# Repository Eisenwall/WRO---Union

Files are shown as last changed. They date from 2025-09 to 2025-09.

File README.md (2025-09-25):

# WRO---Union
# Team Union — Obelix (WRO Future Engineers 2025)

**Project name:** Obelix — Autonomous Robot  
**Team name:** Union  
**Team members:**  
- Abdullah Beshirov — Tester  
- Murad Mehdi — Programmer  
- Jamil Hajizade — Designer  

**GitHub account:** [Eisenwall](https://github.com/Eisenwall)  
**YouTube channel:** N/A  

---

## Project Overview

Our team, Union, has developed **Obelix**, an autonomous robot designed for the **WRO Future Engineers 2025** competition. The primary objective of Obelix is to navigate an obstacle-laden arena autonomously, detect and avoid objects using sensors, and maintain precise movement control with high reliability. Obelix has been developed in two versions: **Obelix 1.0** (prototype) and **Obelix 2.0** (final model). Each version demonstrates progressive improvements in mechanical design, sensor integration, and driving control systems.

We are a dedicated, goal-oriented, and hardworking team. Abdullah Beshirov focused on testing, Murad Mehdi handled programming, and Jamil Hajizade designed the mechanical and aesthetic parts of the robot. Together, we aimed to optimize the robot for maximum efficiency and accuracy on the competition field.

---

## Robot Versions

### Obelix 1.0 (Prototype)

Obelix 1.0 served as the prototype for testing sensor integration, motor control, and mechanical design. Its specifications include:

**Components:**
- **Motors:** 1 × Force-Up 6V 1000 RPM Carbon Brushed DC Motor  
  - Specially manufactured for professional mini sumo robots  
  - High torque and speed suitable for competitions  
  - 6V operating voltage (up to 12V for increased speed and torque)  
  - Specifications:
    - Operating Voltage: 6–12V  
    - Max Voltage: 12V  
    - Speed: 1000 RPM (6V)  
    - No-load Current: 30 mA (6V)  
    - Stall Current: 3.2 A (6V)  
    - Torque: 2.1 kg/cm nominal, 3.7 kg/cm stall  
    - Weight: 9.5 g  
- **Servo:** 1 × SG90 for steering front wheels via **Ackerman steering system**  
- **Ultrasonic Sensors:** 4 × HC-SR04 (1 front, 2 sides, 1 rear)  
- **Color Sensor:** TCS3200, positioned at the front of the robot  
- **Microcontroller:** Arduino Uno  
- **Voltage Regulator:** XL4015 to supply motors with correct voltage  
- **Power Supply:** 2 × Li-ion 18650 for Arduino, 6 × AA batteries for motors  
- **Motor Driver:** TB6612FNG (free-floating due to mechanical design)  
- **Differential system:** Custom LEGO-based differential with three inner gears transmitting motor torque to wheels  
- **Wheels and Steering:** Front wheels connected via Ackerman system using bolts and approximately 40 wires forming tire-like structures using bicycle tube material  

This version used differential drive for two wheels, controlled via the Arduino and color sensor for environmental feedback. The layout optimized sensor placement and power distribution to avoid interference with mechanical components.

---

### Obelix 2.0 (Final Model)

Obelix 2.0 incorporates mechanical and electronic improvements, including:

**Major Upgrades:**
- Replaced Ackerman steering with **Solid Axle Steering system** for increased stability  
- Added a **toggle switch** for motor power control  
- Updated motor: **Force-Up 6V 625 RPM Carbon Brushed DC Motor**  
  - Designed for mini sumo robots with high durability and reliability  
  - Specifications:
    - Operating Voltage: 6–12V  
    - Max Voltage: 12V  
    - Speed: 625 RPM (6V)  
    - No-load Current: 40 mA (6V)  
    - Stall Current: 2.6 A (6V)  
    - Torque: high enough for obstacle navigation  
    - Weight: 9.5 g  

All other components (ultrasonic sensors, color sensor, Arduino Uno, XL4015, battery setup) remained the same. The changes improved maneuverability, stability, and energy efficiency while maintaining the same overall robot footprint.

---

## Folder Structure

obelix/
│
├── obelix 1.0/
│ ├── README.md
│ ├── instructions_to_create.txt
│ ├── how_it_works
│ └── components/
│ └── details.txt (3D models uploaded separately)
│
├── obelix 2.0/
│ ├── new_changes.txt
│ ├── instructions_to_create.txt
│ ├── how_it_works
│ ├── how_it_looks
│ └── components/
│ └── details.txt (3D models uploaded separately)
│
└── README.md (this file)

pgsql
Копировать код

- `obelix 1.0/` contains all prototype documentation, assembly instructions, and 3D models.  
- `obelix 2.0/` includes the latest version documentation, updates compared to 1.0, assembly instructions, and component list.  
- `README.md` summarizes the entire project, robot specifications, and team details.

---

## How It Works

Obelix navigates using **ultrasonic sensors** to measure distances and a **TCS3200 color sensor** to detect markers or lines. Two motors are driven via **differential drive**, while the front wheels steer according to either the Ackerman (1.0) or Solid Axle (2.0) system. The Arduino reads sensor inputs, calculates steering adjustments, and controls motor speed and servo position in real time.

The robot intelligently adjusts its path based on distance changes from obstacles, ensuring efficient navigation and obstacle avoidance. The system handles complex turns and detects objects approaching from different angles.

---

## Sample Arduino Code

```cpp
#include <Servo.h>
Servo myServo;

#define PWMA A3
#define AIN1 A4
#define AIN2 A5

#define TRIG_F 2
#define ECHO_F 3

#define TRIG_R 4
#define ECHO_R 5

#define TRIG_L 6
#define ECHO_L 7

#define TRIG_B 8
#define ECHO_B 9

float prevR = 0, currR = 0, prevL = 0, currL = 0, prevB = 0, currB = 0, prevF = 0, currF = 0;
long duration;
int servoPos = 89;
int stepCount = 0;
int x;
bool xSet = false;

float getDistance(int trigPin, int echoPin) {
  digitalWrite(trigPin, LOW);
  delayMicroseconds(2);
  digitalWrite(trigPin, HIGH);
  delayMicroseconds(10);
  digitalWrite(trigPin, LOW);

  duration = pulseIn(echoPin, HIGH, 20000);
  if(duration == 0) return 9999;
  return (duration * 0.0343) / 2;
}

void setup() {
  pinMode(TRIG_R, OUTPUT);
  pinMode(ECHO_R, INPUT);
  pinMode(TRIG_L, OUTPUT);
  pinMode(ECHO_L, INPUT);
  pinMode(TRIG_B, OUTPUT);
  pinMode(ECHO_B, INPUT);
  pinMode(TRIG_F, OUTPUT);
  pinMode(ECHO_F, INPUT);

  myServo.attach(A2);
  myServo.write(servoPos);
  delay(300);

  pinMode(PWMA, OUTPUT);
  pinMode(AIN1, OUTPUT);
  pinMode(AIN2, OUTPUT);

  digitalWrite(AIN1, HIGH);
  digitalWrite(AIN2, LOW);
  analogWrite(PWMA, 255);

  Serial.begin(9600);
}

void loop() {
  if (stepCount >= 12) {
    analogWrite(PWMA, 0);
    myServo.write(89);
    while (true) {}
  }

  prevR = currR;
  currR = getDistance(TRIG_R, ECHO_R);
  prevL = currL;
  currL = getDistance(TRIG_L, ECHO_L);
  prevB = currB;
  currB = getDistance(TRIG_B, ECHO_B);
  prevF = currF;
  currF = getDistance(TRIG_F, ECHO_F);

  float diffR = currR - prevR;
  float diffL = currL - prevL;
  float diffB = currB - prevB;
  float diffF = currF - prevF;

  if(!xSet){
    if (currL < 18 && currF > currB) x = 1;
    else if (currL < 18 && currF < currB) x = 2;
    else if (currL > 70 && currF < currB) x = 3;
    else if (currL > 70 && currF > currB) x = 4;
    else if (currR < 35 && currF < currB) x = 5;
    else if (currR < 35 && currF > currB) x = 6;
    else if (currR > 55 && currF > currB) x = 7;
    else if (currR > 55 && currF < currB) x = 8;
    xSet = true;
  }

  if(currL > 125 && currB > 150){
    myServo.write(62);
    delay(670);
    servoPos = 89;
    myServo.write(servoPos);
    stepCount++;
  } else if(currR > 125 && currB > 140){
    myServo.write(114);
    delay(670);
    servoPos = 89;
    myServo.write(servoPos);
    stepCount++;
  }

  if (currL < 150 && currR < 150) {
    if(diffR > 0.5 || diffL < -0.5) servoPos = 98;
    else if(diffR < -0.5 || diffL > 0.5) servoPos = 80;
    else servoPos = 89;
    myServo.write(servoPos);
    delay(10);
  }
}

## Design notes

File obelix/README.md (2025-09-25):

# WRO---Union
# Team Union — Obelix (WRO Future Engineers)

**Project name:** Obelix — Self-Driving Car (WRO Future Engineers)  
**Team name:** Union  
**Team members:** Abdullah Beshirov, Murad Mehdi, Jamil Hajizade  
**GitHub account:** Eisenwall  
**Repository structure:** `obelix/` contains `obelix_1.0/` and `obelix_2.0/` folders, documentation and code.

---

## 1. Project overview

This repository contains the design, firmware, mechanical notes and media for the Obelix self-driving vehicle developed by Team Union for the WRO Future Engineers category. The project has two main hardware versions:

- **Obelix 1.0** — initial prototype using Ackerman steering mechanism and the following sensors and components (see Hardware).  
- **Obelix 2.0** — improved final model using Solid Axle Steering system, improved motor and power-switch, structure and wiring improvements. The `obelix_2.0/new_changes` folder documents differences compared to Obelix 1.0.

The focus of the project is robust autonomous lane keeping, pillar (traffic sign) recognition (colour classification), obstacle avoidance using ultrasonic sensors, and reliable parallel parking manoeuvre. All documentation and source code included here aims to be reproducible for other teams.

---

## 2. Team and responsibilities

- **Abdullah Beshirov** — mechanical assembly, differential and drivetrain  
- **Murad Mehdi** — sensors integration, electronics wiring, power management  
- **Jamil Hajizade** — firmware, algorithms (obstacle avoidance and parking), repository & documentation

---

## 3. Short summary of Obelix 1.0 and 2.0

**Obelix 1.0 (prototype)**  
- Steering: **Ackerman steering mechanism** for front wheels.  
- Drive: differential power applied to the rear axle via a LEGO-based differential assembly. Two driving wheels powered by a single driving axle with differential gearing derived from LEGO parts (small gear + cross shafts).  
- Motors: 1 × *Force-Up 6V 1000 RPM* brushed DC motor (high torque).  
- Steering servo: 1 × SG90 (controls front pair via Ackerman linkages).  
- Sensors: 4 × HC-SR04 ultrasonic sensors (front, left, right, rear), 1 × TCS3200 color sensor (front).  
- Controller: **Arduino Uno** (main control and sensor reading).  
- Motor driver: **TB6612FNG** (drives DC motor; mounted on the chassis but not rigidly fixed).  
- Power: 2 × 18650 Li-ion cells for Arduino power and 6 × AA batteries for motor supply; XL4015 module used for regulating motor supply where necessary.  
- Chassis, tires: custom chassis, drive shafts and a tire made from bicycle camera rubber for traction.

**Obelix 2.0 (final)**  
- Steering: **Solid Axle Steering** (mechanically simpler and more robust). Ackerman replaced.  
- Motor replaced with **Force-Up 6V 625 RPM** (lower RPM, higher torque).  
- Added main toggle switch (tumbler) for motor on/off.  
- Wiring, cabling and battery sockets reorganised for reliability.  

---

## 4. Hardware (detailed list)

All components (more details in `obelix/*/components/details.txt`):

- Arduino UNO — 1 pcs  
- HC-SR04 Ultrasonic sensor — 4 pcs (front, left, right, rear)  
- TCS3200 Color sensor — 1 pcs (front)  
- SG90 micro servo — 1 pcs (steering for Obelix 1.0)  
- Force-Up DC Motor (6V, 1000 RPM) — Obelix 1.0 — 1 pcs  
- Force-Up DC Motor (6V, 625 RPM) — Obelix 2.0 — 1 pcs  
- Motor driver TB6612FNG — 1 pcs  
- XL4015 (step-down / current regulator) — 1 pcs  
- Li-ion 18650 battery holder / 2 cells — 1 set (for Arduino)  
- AA battery holder (6×AA) — 1 set (for motor pack)  
- Breadboard (partial removed piece used in chassis) — small section mounted on back  
- Mechanical parts: LEGO differential piece + cross axles, custom links for Ackerman, bolts (Ø3mm × 15mm and smaller), cable ties, wheel rims, rubber tyre (from bicycle camera)  
- Cables: ~40 wires used for traction banding and wiring

(See `BOM.csv` for table version.)

---

## 5. Software architecture and files

This project uses a single microcontroller (Arduino Uno) as main controller for both sensors and actuators. The code is organized as:

/code  
/arduino  
obelix.ino <-- main firmware  
drive_control.h/.cpp  
sensors.h/.cpp  
config.h <-- pin mapping, thresholds and calibration constants  

/tools  
serial_logger.py <-- optional serial log viewer (desktop)

**Main behaviour (firmware)**:  
- Read sensors (HC-SR04 x4, TCS3200)  
- Low-level motor control through TB6612FNG (PWM and direction)  
- Steering control through SG90 (PWM for Ackerman) or Solid Axle linkage in v2.0  
- Finite state machine for: `WAIT_START -> LANE_FOLLOW -> PILLAR_HANDLING -> PARKING_MANEUVER -> STOP`  
- Logging via Serial (for debug)

---

## 6. Pin mapping (recommended, edit `config.h` as needed)

- HC-SR04 front: TRIG D2, ECHO D3  
- HC-SR04 left: TRIG D4, ECHO D5  
- HC-SR04 right: TRIG D6, ECHO D7  
- HC-SR04 rear: TRIG D8, ECHO D9  
- TCS3200 S0..S3: D10..D13 (or analog read if using frequency counting)  
- Servo: D11 (PWM)  
- TB6612FNG: PWM_A D5, AIN1 D12, AIN2 D13 (adjust as needed)  
- Start push button: digital pin A0 (if used)

---

## 7. How to build / compile / upload (Arduino)

1. Install Arduino IDE (latest stable).  
2. Open `code/arduino/obelix.ino`.  
3. Edit `config.h` to match your wiring (pins and battery voltages).  
4. Select board `Arduino Uno`, correct COM port.  
5. Compile and Upload.  
6. Place robot in starting zone, switch batteries on, press start (or send serial start if configured).

---

## 8. Tests, videos and performance

**Videos:** Put links in `videos.txt` and in this README when uploaded (YouTube unlisted/public). Each challenge must have at least one demo ≥30 seconds.

**Expected Behaviours:**  
- Lane follow stable (tested on practice mat)  
- Pillar detection via TCS3200 (red vs green classification)  
- Parallel parking routine triggered after lap completion

---

## 9. Reproducibility & files to reproduce the build

- `obelix_1.0/components/details.txt` — component list and small CAD notes  
- `obelix_1.0/instructions_to_create.txt` — assembly guide (mechanical connections, bolts, link lengths)  
- `obelix_2.0/new_changes/*` — changes from 1.0 to 2.0  
- `/models` — STL / CAD files (3D models to be uploaded)  
- `docs/wiring_diagram.png` — wiring diagram (add when available)

---

## 10. Commit history requirements (WRO)

- Commit 1 — not later than 2 months before competition (≥20% of final code)  
- Commit 2 — not later than 1 month before competition  
- Commit 3 — not later than 2 weeks before competition  

Repository must be **public** for at least 12 months.

---

## 11. Licence & credits

- MIT License (`LICENSE`)  
- Hardware components: suppliers listed in BOM  
- Team-built mechanical parts and software modules credited in `CREDITS.md`

---

## 12. Contact

Team Union — Team Captain: Jamil Hajizade — `<<team.email@example.com>>`

---

# Engineering Journal — Team Union — Obelix

**Team:** Union  
**Robots:** Obelix 1.0 (prototype), Obelix 2.0 (final)  
**Authors:** Abdullah Beshirov, Murad Mehdi, Jamil Hajizade  

---

## Entry 1 — Mobility Management (design & choices)
**Date:** 2025-09-25  
**Goal:** Design reliable drivetrain and steering that meet WRO rules (4 wheels, one driving axle, one steering actuator).  

**Components used:**  
- Drive motor (Obelix 1.0): Force-Up 6V 1000 RPM  
- Drive motor (Obelix 2.0): Force-Up 6V 625 RPM  
- Differential assembly: LEGO differential piece + cross shafts  
- Steering: SG90 + Ackerman linkage (v1.0); Solid Axle (v2.0)  

**Design rationale:**  
- Single driving axle with differential complies with WRO rules. LEGO differential allows independent wheel rotation.  
- Ackerman servo used for simplicity; replaced with Solid Axle for repeatable steering in final version.  
- Bicycle camera rubber used on rims for traction.  

**Testing:**  
- 10 straight runs at 6V; corrected slight right drift by adjusting servo and mounting.  
- Overheating risk tested; duty cycles recommended.

---

## Entry 2 — Power & Sensor Management
**Date:** 2025-09-25  
**Power system:**  
- Arduino: 2 × 18650 Li-ion (regulated).  
- Motors: 6 × AA batteries, TB6612FNG, XL4015 for regulation.  
- Obelix 2.0: added main toggle switch.  

**Sensors:**  
- HC-SR04 x4 for obstacle detection (front, left, right, rear)  
- TCS3200 for pillar colour detection  

**Testing & measurements:**  
- Idle motor current ~30–40 mA; stall 2.6–3.2 A  
- Ultrasonic reliable for 5–200 cm, filtered in firmware  

---

## Entry 3 — Obstacle Management & Algorithms
**Date:** 2025-09-25  
**Goal:** Describe obstacle and parking strategy  

**Strategy summary:**  
- Finite state machine:  
  - `START` → `FOLLOW_LANE` → while laps < 3: `PILLAR_RESPONSE` → if lap_complete: `PARKING_SEQUENCE` → `STOP`  
- PILLAR_RESPONSE:  
  - TCS3200 reads pillar colour  
  - GREEN → left-bias trajectory  
  - RED → right-bias trajectory  
- LANE FOLLOW:  
  - Ultrasonic left+right sensors for lane centering  
  - Front sensor for obstacle proximity  
- PARKING:  
  - Predefined parallel parking trajectory using distances (coordinate-free)

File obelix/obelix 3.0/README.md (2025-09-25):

# Team Union — Obelix 3.0 (WRO Future Engineers)

**Project name:** Obelix 3.0 — Self-Driving Car (WRO Future Engineers)  
**Team name:** Union  
**Team members:** Abdullah Beshirov, Murad Mehdi, Jamil Hajizade  
**GitHub account:** Eisenwall

It will be the third version of the robot
We divided it into three versions:
obelix 3.0 (basic version) and obelix 3.0 modified
## ⚙️ Comparison Table

| Feature | Obelix 3.0 (Basic) | Obelix 3.0 Modified |
|---|---|---|
| Ultrasonic sensors | 2 (front on servo + rear fixed) | None |
| Color sensor | TCS3200 + lens (on servo) | None |
| Camera | No | OV2640 (ESP32-CAM) / Pi Camera v3 |
| Microcontroller | Arduino Uno / Mega | ESP32-CAM / Raspberry Pi 4 |
| Motors | NovaMax Enkoderli 6V 500 RPM | NovaMax Enkoderli 6V 500 RPM |
| Switch | ON/OFF switch | ON/OFF switch |
| Servos | SG90 (ultrasonic + TCS3200) | SG90 (camera pan) |

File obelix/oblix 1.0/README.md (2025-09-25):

## Obelix 1.0 — Prototype
The first version of our robot was mainly focused on testing ideas and validating the base concept.  
- **Pros:**  
  - Ackerman steering system allowed good maneuverability.  
  - High-speed 1000 RPM motor provided fast movement.  
  - Easy to assemble with LEGO-based differential and 3D printed parts.  
- **Cons:**  
  - Steering system was unstable and hard to control at higher speeds.  
  - Battery and wiring layout was less practical.  
  - Robot was less reliable for long runs.

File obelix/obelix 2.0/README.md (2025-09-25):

## Obelix 2.0 — Final Model
The second version was redesigned to be more stable, reliable, and competition-ready.  
- **Pros:**  
  - Solid Axle Steering improved handling and overall stability.  
  - 625 RPM motor offered better torque and smoother control.  
  - Added power switch for easier operation.  
  - Improved design with corrected weight distribution.  
  - More durable mechanical structure.  
- **Cons:**  
  - Slightly lower top speed compared to 1.0.  
  - Assembly became more complex due to added features.

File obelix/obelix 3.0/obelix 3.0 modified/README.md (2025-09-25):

## 🔹 Obelix 3.0 Modified (Advanced Version)

**Changes compared to Obelix 3.0 Basic:**
- Removed **ultrasonic sensors** and **TCS3200 color sensor**.  
- Added **camera system** for object detection and navigation.  
- New microcontroller:  
  - **ESP32-CAM** with OV2640 camera (budget option).  
  - or **Raspberry Pi 4 + Pi Camera Module v3 (12MP, autofocus)** for advanced image processing.  
- Camera can be mounted on **SG90 servo** for dynamic field of view.  
- Motors: **NovaMax Enkoderli 6V 500 RPM Mikro DC Motor** with encoder.  
- Power switch: **ON/OFF switch**.

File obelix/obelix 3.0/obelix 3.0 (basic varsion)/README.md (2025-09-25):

## 🔹 Obelix 3.0 (Basic Version)

**Changes compared to Obelix 2.0:**
- Replaced **4 ultrasonic sensors** with **2 ultrasonic sensors (HC-SR04)**:  
  - One mounted on **SG90 servo**, rotating for scanning.  
  - One fixed, facing backwards.  
- Added **TCS3200 color sensor** with **magnifying lens** for long-range color detection (mounted on SG90 servo).  
- Replaced **toggle switch** with **ON/OFF switch**.  
- Replaced motors with **NovaMax Enkoderli 6V 500 RPM Mikro DC Motor**:  
  - Built-in encoder for precise speed and position control.  
  - Torque: 3.5 kg/cm.  
- Microcontroller: **Arduino Uno / Mega**.

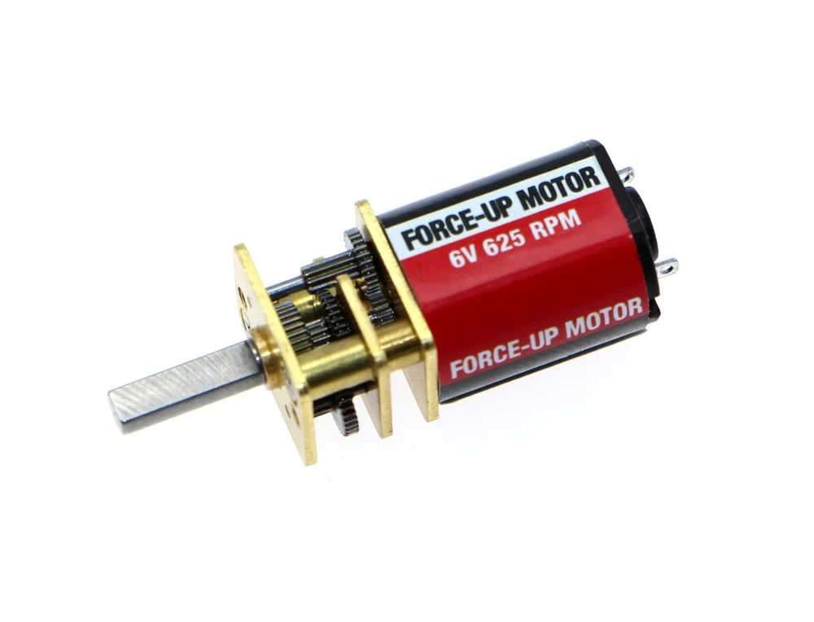
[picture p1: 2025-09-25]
images/force-up-6v-625-rpm.webp

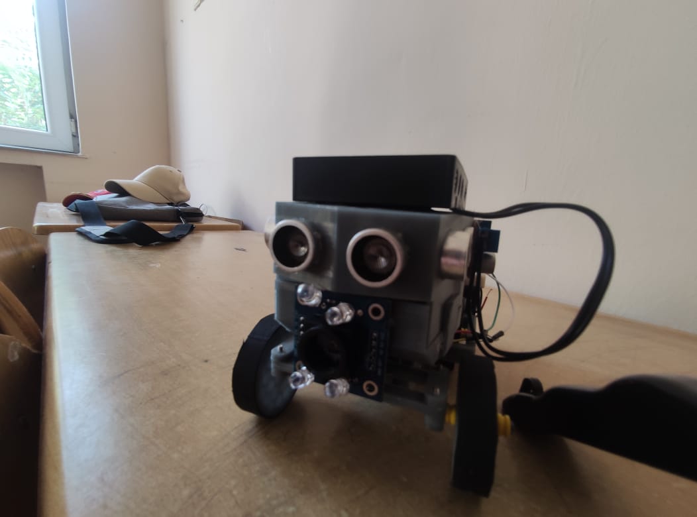
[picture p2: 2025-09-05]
obelix/oblix 1.0/our robot.jpeg

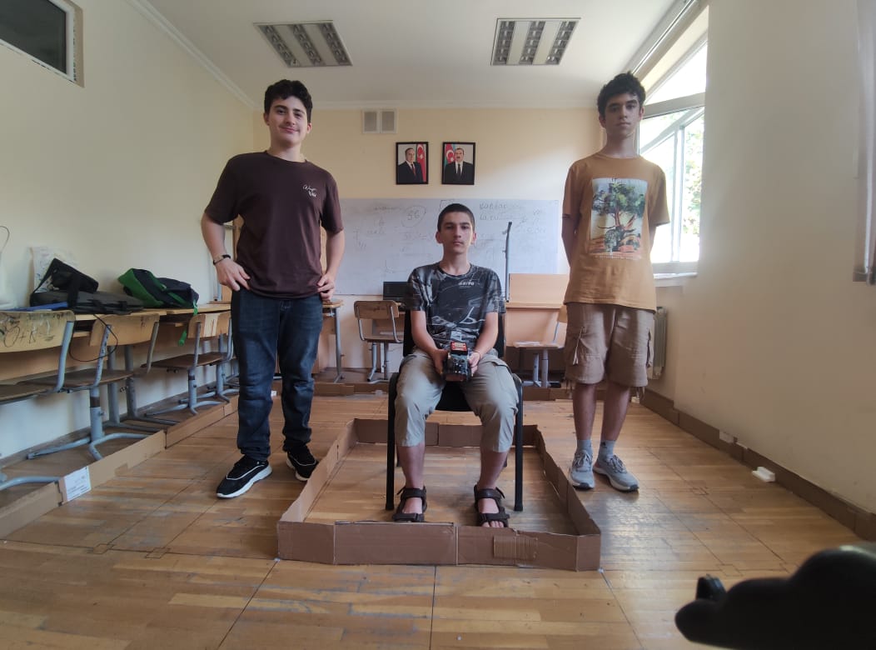
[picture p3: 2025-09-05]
Our team/our team.jpeg

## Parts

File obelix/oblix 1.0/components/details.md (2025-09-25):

# Obelix 1.0 — Components List with Images

This file lists all components used in Obelix 1.0, including mechanical, electronic, and sensor parts. Images are placeholders; you can replace them with actual photos or 3D renders.

---

## 1. Motors
**Type:** Force-Up 6V 1000 RPM Carbon Brushed DC Motor  
**Quantity:** 1  
**Description:** High torque motor designed for mini sumo robots. Drives two wheels via differential.  
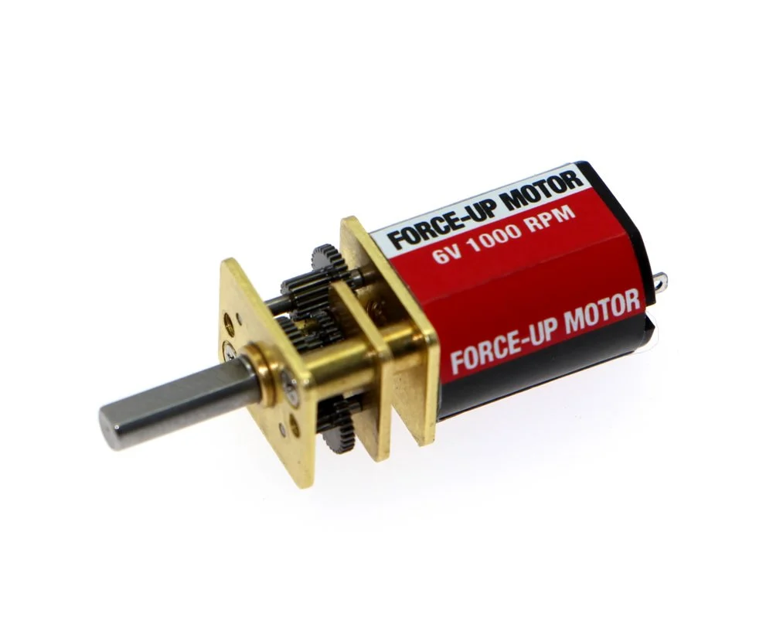
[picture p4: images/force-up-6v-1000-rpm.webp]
Motor
**Image:**   

---

## 2. Servo
**Type:** SG90 Micro Servo  
**Quantity:** 1  
**Description:** Controls front wheels via Ackerman steering system.  
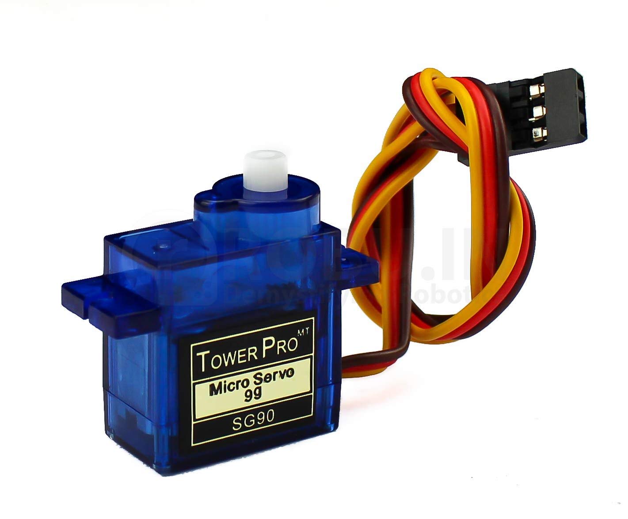
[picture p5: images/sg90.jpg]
Servo
**Image:**   

---

## 3. Ultrasonic Sensors
**Type:** HC-SR04  
**Quantity:** 4  
**Description:** Measures distance to obstacles. Placement: 1 front, 2 sides, 1 rear.  
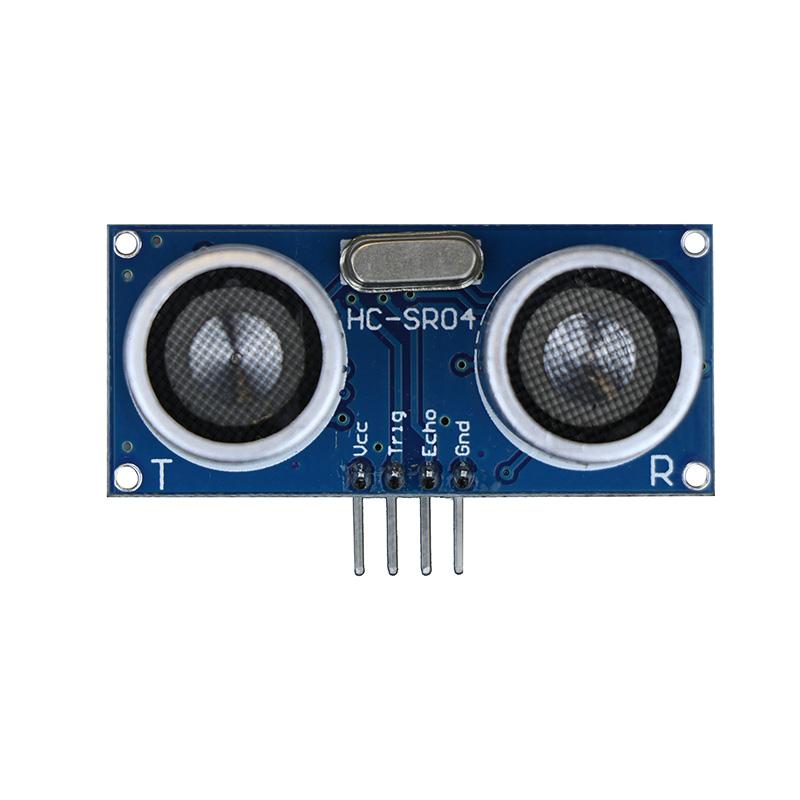
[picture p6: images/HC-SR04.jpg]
Ultrasonic Sensor
**Image:**   

---

## 4. Color Sensor
**Type:** TCS3200  
**Quantity:** 1  
**Description:** Detects colors/lines in front of the robot.  
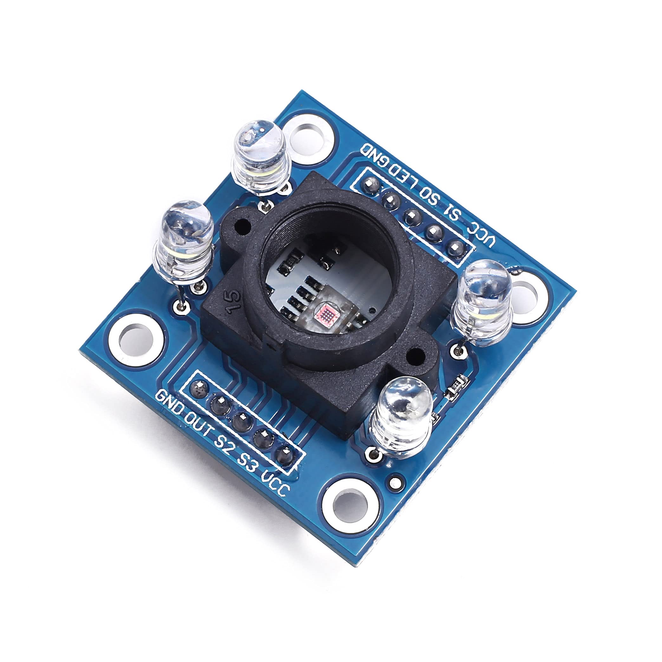
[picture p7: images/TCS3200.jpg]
Color Sensor
**Image:**   

---

## 5. Microcontroller
**Type:** Arduino Uno  
**Quantity:** 1  
**Description:** Controls motors, sensors, and servo. Executes navigation algorithms.  
Arduino Uno
**Image:**   

---

## 6. Motor Driver
**Type:** TB6612FNG  
**Quantity:** 1  
**Description:** Controls motor speed and direction. Mounted freely due to mechanical layout.  
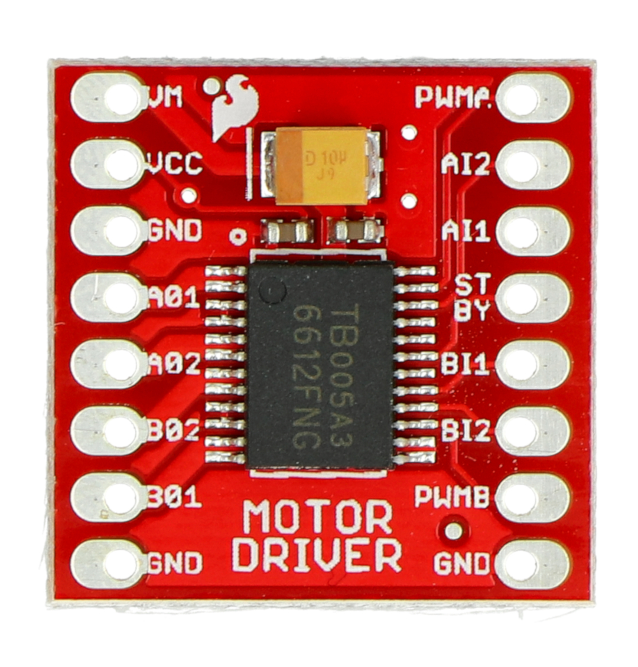
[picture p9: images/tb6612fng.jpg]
Motor Driver
**Image:**   

---

## 7. Voltage Regulator
**Type:** XL4015  
**Quantity:** 1  
**Description:** Supplies appropriate voltage to the motors from battery pack.  
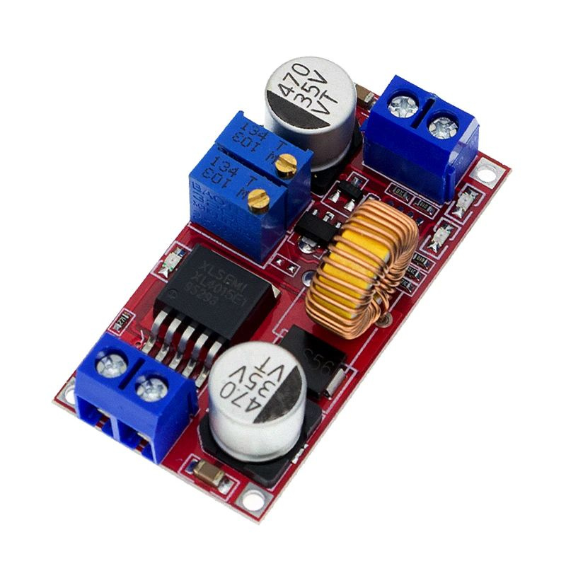
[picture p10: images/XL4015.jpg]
Voltage Regulator
**Image:**   

---

## 8. Power Supply
- **Li-ion 18650 batteries:** 2 (for Arduino)  
- **AA batteries:** 6 (for motors)  
- **Battery holders:** 2 (one for Li-ion, one for AA pack)

---

## 9. Wheels and Differential
**Type:** Custom LEGO differential  
**Quantity:** 1 differential assembly + 2 front wheels  
**Description:** Differential distributes motor torque to two wheels; front wheels steered via servo.  
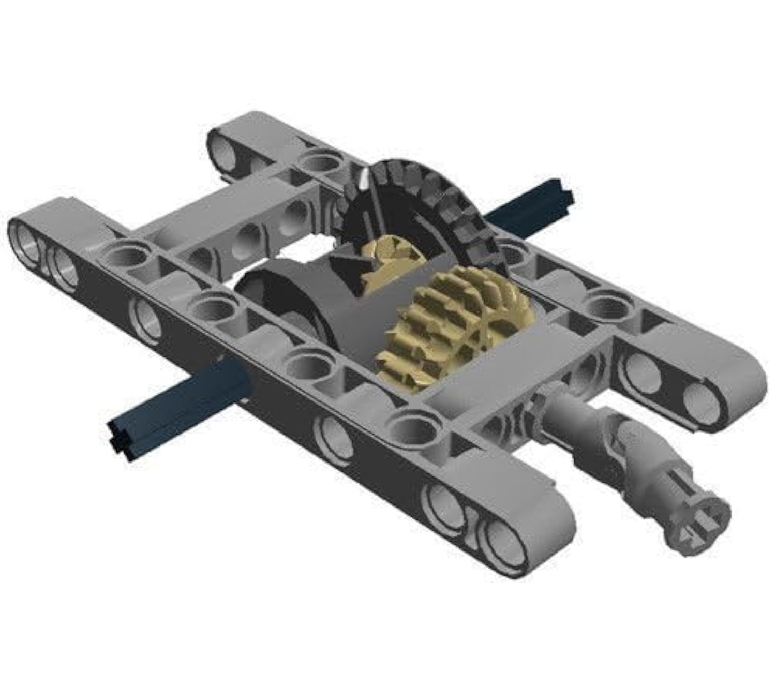
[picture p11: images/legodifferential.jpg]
Differential
**Image:**   

---

## 10. Mechanical Parts for Steering
**Components:**  
- 2 × 3mm × 15mm bolts for front wheels  
- 6 smaller bolts for assembling Ackerman linkage  
- 2 long cross-shaped LEGO rods for differential connection

---

## 11. Wires
**Quantity:** ~40  
**Description:** Connect sensors, servo, motor driver, and Arduino. Some wires used as tires (from bicycle tube material).

---

## 12. Breadboard Parts
**Components:** GND, VCC, and connection points for XL4015, Arduino, and sensors.  
**Description:** Used to organize power and signal connections.  
**Image:** Breadboard  

---

**Notes:**  
- 3D models for mechanical parts are uploaded separately in the `components/` folder.  
- Images here are placeholders; replace with actual photos or renders for GitHub visualization.

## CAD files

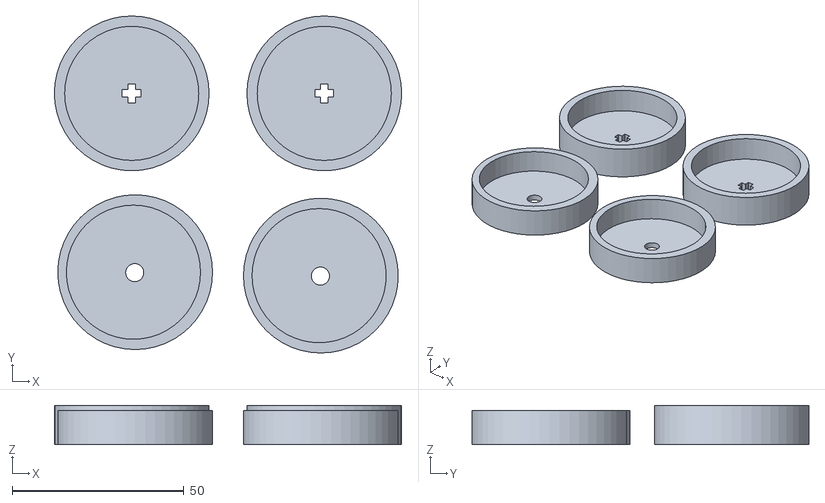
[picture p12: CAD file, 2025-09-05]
files and details to create obelix 1.0/3d models/forward and back wheels(1).stl
101.0 x 98.0 x 11.4

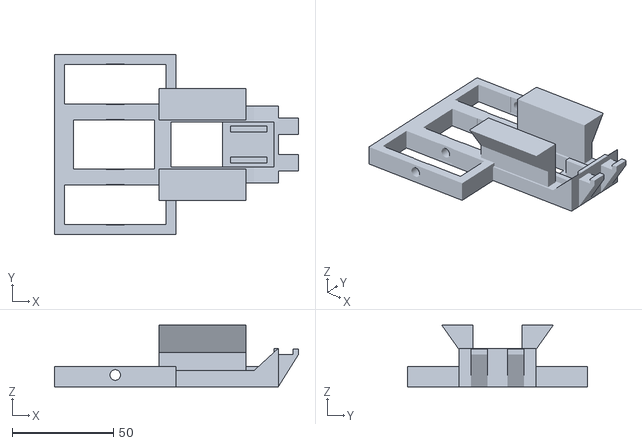
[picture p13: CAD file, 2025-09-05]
files and details to create obelix 1.0/3d models/buttompart(1).stl
120.5 x 89.0 x 30.5

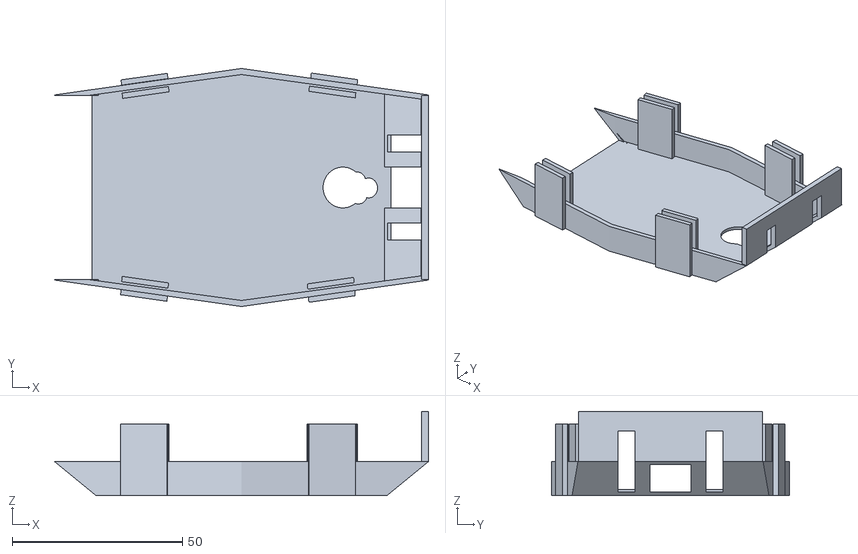
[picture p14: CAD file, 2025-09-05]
files and details to create obelix 1.0/3d models/middlepart(1).stl
110.0 x 70.0 x 24.8

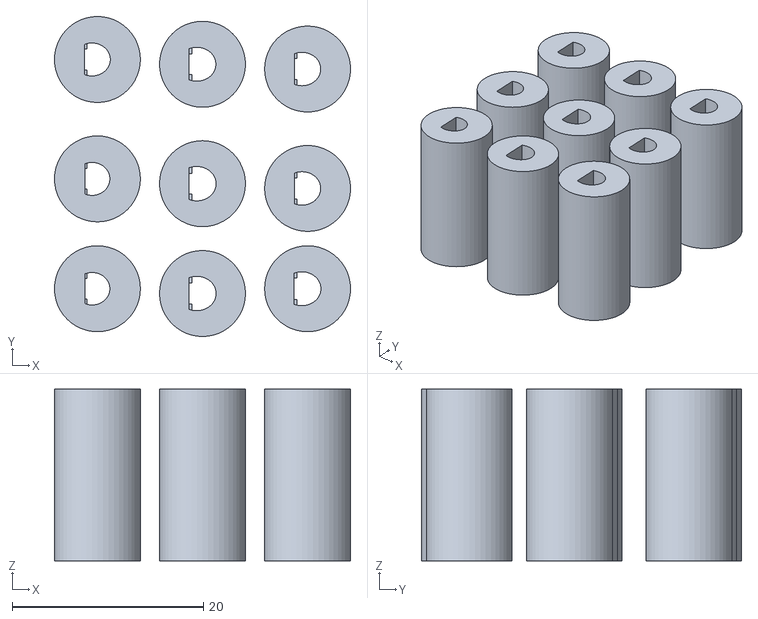
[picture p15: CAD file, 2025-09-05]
files and details to create obelix 1.0/3d models/converter for motor(1).stl
31.0 x 33.5 x 18.0

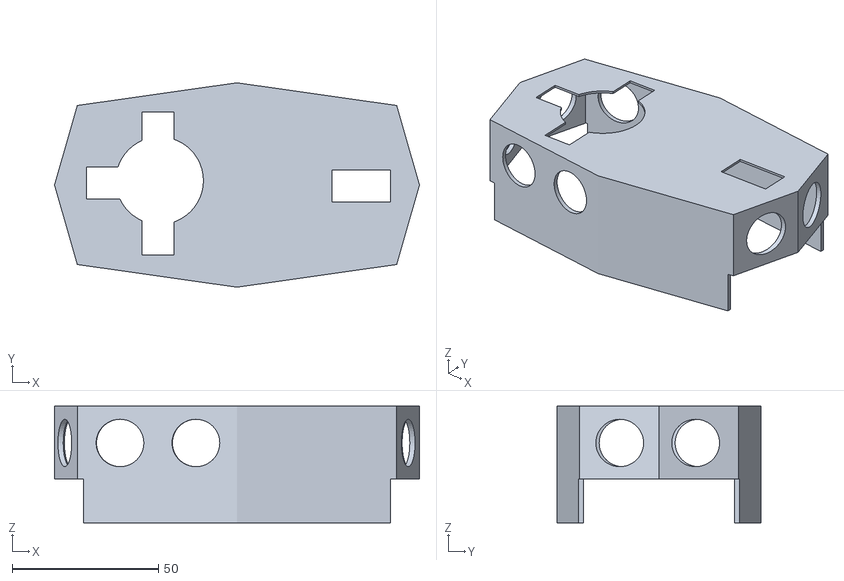
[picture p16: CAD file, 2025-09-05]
files and details to create obelix 1.0/3d models/toppart(1).stl
125.0 x 70.0 x 40.0

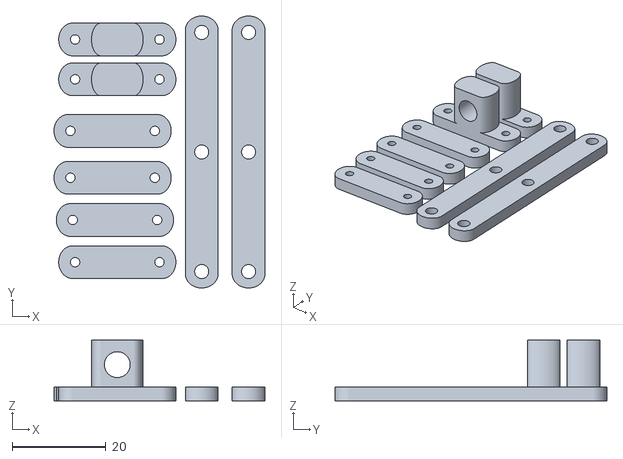
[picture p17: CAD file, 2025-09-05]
files and details to create obelix 1.0/3d models/details for turning0(1).stl
45.0 x 58.0 x 13.0

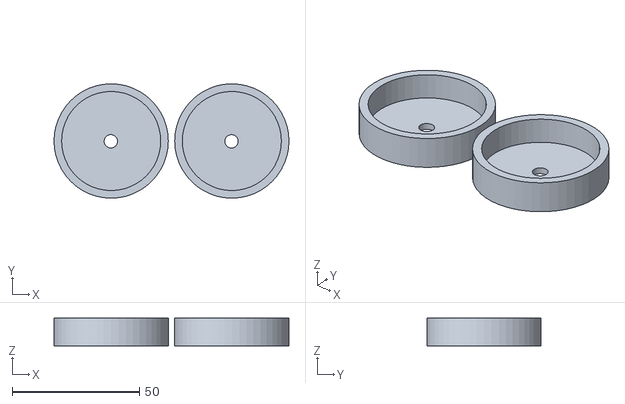
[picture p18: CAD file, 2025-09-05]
files and details to create obelix 1.0/3d models/forward wheels(1).stl
92.5 x 45.0 x 11.0

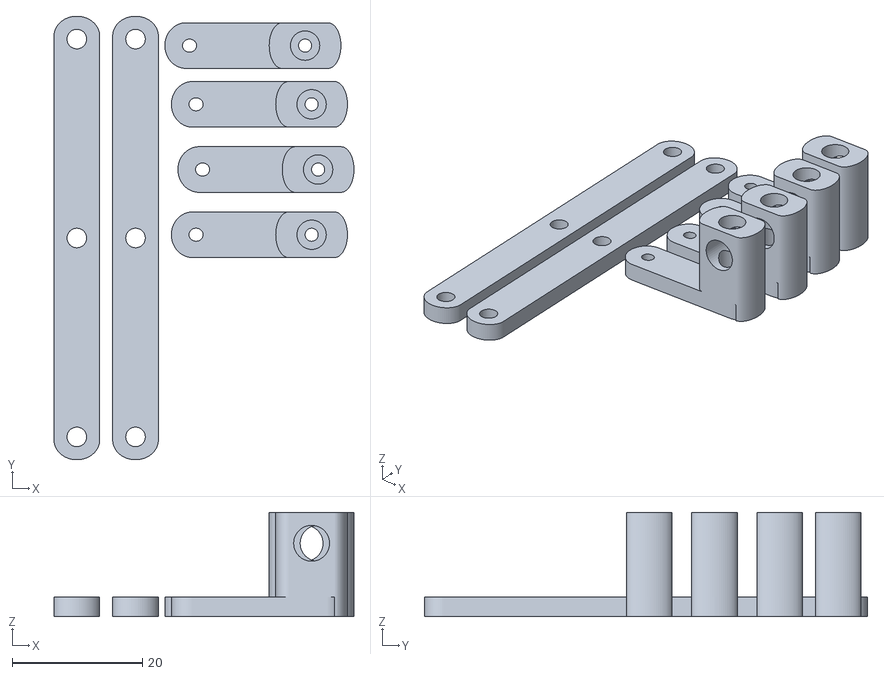
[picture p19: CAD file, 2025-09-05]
files and details to create obelix 1.0/3d models/details for turning1(1).stl
46.0 x 68.0 x 16.0

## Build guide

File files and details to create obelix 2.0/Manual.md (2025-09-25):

# How to Build Obelix 2.0

This guide explains how to create our robot step by step.

---

## 1. Components Required

Before starting, make sure you have the following components:

- **Servomotor:** SG90  
- **DC Motor:** Force-Up 6V 650 RPM Carbon Brushed DC Motor  
- **Motor Driver:** TB6612FNG  
- **Microcontroller:** Arduino Uno  
- **Ultrasonic Sensors:** 4 × HC-SR04  
- **Color Sensor:** TCS3200  
- **Accumulators (Batteries):** 2 (one for the motors, one for Arduino)  
- **Cables:** Appropriate Arduino cables  
- **Wheels:** You can use old camera tires or similar for the robot wheels  
- **Optional:** DC-DC converter for voltage regulation, BMS module to protect your batteries  

---

## 2. 3D Printed Parts

You will need to 3D print the following components for your robot:

- **Bottom Part (Corpus Base):**  
  [buttompart.stl](https://github.com/Eisenwall/WRO---Union/blob/main/files%20and%20details%20to%20create%20obelix%202.0/3d%20models/buttompart.gx)  

- **Motor Converter (Connect Motors to LEGO Parts):**  
  [converter for motor.stl](https://github.com/Eisenwall/WRO---Union/blob/main/files%20and%20details%20to%20create%20obelix%202.0/3d%20models/adapters.gx)   

- **Wheels:**  
  [forward and back wheels.stl](https://github.com/Eisenwall/WRO---Union/blob/main/files%20and%20details%20to%20create%20obelix%202.0/3d%20models/wheels.gx)

- **Middle Part of Robot:**  
  [middlepart.stl](https://github.com/Eisenwall/WRO---Union/blob/main/files%20and%20details%20to%20create%20obelix%202.0/3d%20models/middpart.stl)  

- **Top Part of Robot:**  
  [toppart.stl](https://github.com/Eisenwall/WRO---Union/blob/main/files%20and%20details%20to%20create%20obelix%202.0/3d%20models/top-part.stl)  

---

## 3. Assembly Notes

1. Start by printing all 3D parts and checking their fit.  
2. Assemble the bottom part first, then attach the middle and top parts.  
3. Install motors and connect them via the motor converter.  
4. Mount the wheels and check for smooth rotation.  
5. Install sensors (ultrasonic and color) in their respective positions.  
6. Connect the Arduino and motor driver using the cables.

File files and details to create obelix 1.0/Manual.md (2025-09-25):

# How to Build Obelix Robots

This guide explains how to create both versions of our robot step by step. Instructions for **Obelix 1.0** (prototype) and **Obelix 2.0** (final model) are provided separately.

---

## Obelix 1.0 — Prototype

### 1. Components Required

- **Servomotor:** SG90  
- **DC Motor:** Force-Up 6V 1000 RPM Carbon Brushed DC Motor  
- **Motor Driver:** TB6612FNG  
- **Microcontroller:** Arduino Uno  
- **Ultrasonic Sensors:** 4 × HC-SR04  
- **Color Sensor:** TCS3200  
- **Accumulators (Batteries):** 2 (one for motors, one for Arduino)  
- **Cables:** Appropriate Arduino cables  
- **Wheels:** Old camera tires or similar  
- **Optional:** DC-DC converter for voltage regulation, BMS module for battery protection  

### 2. 3D Printed Parts

- **Bottom Part (Corpus Base):** [https://github.com/Eisenwall/WRO---Union/blob/main/files%20and%20details%20to%20create%20obelix/buttompart.stl]  
- **Motor Converter:** [https://github.com/Eisenwall/WRO---Union/blob/main/files%20and%20details%20to%20create%20obelix/converter%20for%20motor.stl]  
- **Turning Mechanism Parts1:** [https://github.com/Eisenwall/WRO---Union/blob/main/files%20and%20details%20to%20create%20obelix/details%20for%20turning0.stl]
- **Turning Mechanism Parts2:** [https://github.com/Eisenwall/WRO---Union/blob/main/files%20and%20details%20to%20create%20obelix/details%20for%20turning1.stl] 
- **Wheels:** [https://github.com/Eisenwall/WRO---Union/blob/main/files%20and%20details%20to%20create%20obelix/forward%20and%20back%20wheels.stl]  
- **Middle Part of Robot:** [https://github.com/Eisenwall/WRO---Union/blob/main/files%20and%20details%20to%20create%20obelix/middlepart.stl]  
- **Top Part of Robot:** [https://github.com/Eisenwall/WRO---Union/blob/main/files%20and%20details%20to%20create%20obelix/toppart.stl]  

### 3. Assembly Notes

1. Print all 3D parts and verify fit.  
2. Assemble the **bottom part first**, then attach the **middle** and **top parts**.  
3. Install motors and connect them via the motor converter.  
4. Mount the wheels and check for smooth rotation.  
5. Install sensors (ultrasonic and color) in the designated positions.  
6. Connect the Arduino and motor driver using cables.  
7. Mount the servo for **Ackerman steering** to control the front wheels.  
8. Arrange batteries and power connectors so they do not interfere with wheels or sensors.

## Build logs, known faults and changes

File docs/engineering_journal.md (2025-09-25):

# Engineering Journal — Team Union / Robot OBELIX
**Team name:** Union  
**Team members:** Abdullah Beshirov, Murad Mehdi, Jamil Hajizade  
**Robot name:** Obelix (Obelix 1.0 — prototype; Obelix 2.0 — final)

---

## Summary
This engineering journal documents the development process of the autonomous WRO vehicle **Obelix**. The project progressed through an initial prototype (Obelix 1.0) and a final model (Obelix 2.0). The primary focus was on mobility (steering & drive), sensor fusion (ultrasonic array + color sensor + IMU/encoders) and robust obstacle management including parallel parking.

---

## Entry 1 — 2025-09-15 — Project start and Obelix 1.0 prototype
**Goal:** Build prototype to validate mechanical layout, steering concept (Ackermann), basic sensing and drive.  
**Hardware used:**
- 4× HC-SR04 ultrasonic sensors (front, left, right, rear)
- 1× SG90 micro servo (for steering Ackermann linkage)
- 1× Force-Up 6V 1000 RPM brushed DC motor (drive)
- 1× TB6612FNG motor driver
- 1× Arduino UNO (SBM)
- 1× TCS3200 colour sensor (front)
- 1× XL4015 (DC-DC supply module for motors)
- 2× 18650 Li-ion cells (for Arduino) + 6× AA batteries for motors
- LEGO differential parts for the differential system, various bolts, bicycle inner-tube for tires
- Breadboard, wires, connectors

**Actions:**
1. Assembled RC chassis with LEGO differential part and wheel mounts. Used D-shaft connectors and bolts (3 mm × 15 mm) to attach front axle members and steering linkages.
2. Implemented Ackermann steering with SG90 servo controlling two front wheels via linkage.
3. Wired 4 HC-SR04 sensors (trigger/echo) to Arduino digital pins and added basic filtering on measured distances (median of 3 readings).
4. Integrated TCS3200 in front for pillar color detection; tuned frequency scaling and measured raw R/G/B pulses.
5. Configured TB6612FNG to drive main motor through XL4015-regulated supply.
6. First tests: simple forward/back and turn; basic obstacle avoidance state machine implemented on Arduino.

**Results:**
- Prototype moved and steered, basic object detection worked reliably at 20–40 cm for HC-SR04.
- Color sensor recognized red/green pillars under controlled light (ambient light affects thresholds).
- Main issues: Ackermann steering introduced alignment complexity; TB6612FNG current peaks caused supply drop under stall — needed smoothing capacitor and proper ground returns.

**Conclusion / Next steps:**
- Improve power decoupling; measure current draw during stall.
- Replace Ackermann with a more robust steering for final model (or redesign steering geometry).
- Prepare detailed wiring diagram and BOM.

**Photos & Video:** `../photos/obelix_1_front.jpg`, `../photos/obelix_1_top.jpg`  
**Video (prototype):** `<<YouTube link placeholder>>`

---

## Entry 2 — 2025-09-21 — Mobility tuning & power management
**Goal:** Stabilize drive motor behaviour, tune wheel mounting, add power switch and updated motor choice for Obelix 2.0.  
**Hardware changes for Obelix 2.0:**
- Drive motor replaced with **Force-Up 6V 625 RPM** (lower RPM, higher torque at nominal voltage).
- Steering changed from Ackermann to **Solid Axle Steering** (rigid steering shaft + single servo or servo-gear steering rack).
- Added main motor power toggle switch (tumbler) and proper motor battery connector on robot roof.
- Re-positioned Li-ion battery socket to rear for CG balance.

**Actions:**
1. Replaced motor and tested free-run and loaded RPM at nominal 6 V. Logged no-load current ~40 mA and stall/starting current ~2.6 A (measured roughly by multimeter).
2. Reworked wiring: separate motor battery pack (6×AA) and SBC/Arduino supply with XL4015 + decoupling capacitors.
3. Mounted motor driver TB6612FNG on small perfboard and secured to chassis using nylon ties — kept accessible but mechanically stable.
4. Redesigned wheel mounts and differential coupling using LEGO differential internals with D-shaft adapter; ensured alignment to avoid binding.

**Measurements / Results:**
- Effective forward speed (measured by wheel circumference 0.1885 m at 625 RPM) ≈ 1.95 m/s theoretical free-run; loaded speed ~1.2 m/s in practice.
- Steering repeatability improved using solid axle; turning radius consistent across runs.
- Power supply stability improved after adding 470 µF electrolytic capacitor across motor terminals and 10 mF bulk across battery connector.

**Conclusion / Next steps:**
- Finalize mechanical mounts for motors and servo to secure under competition handling.
- Prepare complete wiring diagram and BOM for upload to GitHub.
- Move sensor thresholds to config file for easy tuning.

**Photos:** `../photos/obelix_2_side.jpg`, `../photos/obelix_2_rear.jpg`  
**Video (mobility tests):** `<<YouTube link placeholder>>`

---

## Entry 3 — 2025-09-23 — Sensor fusion & obstacle management
**Goal:** Integrate HC-SR04 array + TCS3200 + encoder feedback into decision logic for obstacle challenge and parking routine.  
**Software summary:**
- Obstacle management implemented as FSM (Finite State Machine) with states: IDLE → LINE_FOLLOW → PILLAR_DETECT → PASS_PILLAR → LAP_COMPLETE → PARK.
- Pillar classification uses TCS3200 thresholds: RED if R_ratio > 0.60 and R_abs > 200; GREEN if G_ratio > 0.60 and G_abs > 200 (example thresholds — adjust during testing).
- Distance gating: HC-SR04 front triggers braking when object < 12 cm; side sensors used to maintain lateral clearance.

**Actions:**
1. Implemented serial protocol between Raspberry Pi (if used in SBC setup) / Arduino or standalone Arduino state machine to combine sensor inputs.
2. Added simple encoder counter on motor axle for odometry coarse estimation (counts per wheel rotation recorded).
3. Implemented parallel parking routine triggered after lap count; parking uses ultrasound to detect parking marker limits and steering to align parallel to boundary.

**Results:**
- In 10 runs, pillar detection accuracy ≈ 92% in indoor lighting; false positives during reflective ambient light.
- Parallel parking success (fully inside bay) = 7/10 in test configuration with mock parking markers.
- Logs saved to `/logs` (timestamped csv) containing sensor readings and state transitions for later analysis.

**Conclusion / Next steps:**
- Improve TCS3200 ambient light compensation (add simple hood or calibration routine).
- Tune PID on drive to reduce overshoot in parking manoeuvre.
- Finalize and push all code with extensive comments to GitHub and ensure at least 3 commits.

**Photos & Schematics:** `../docs/wiring_diagram.png`  
**Video (obstacle & parking):** `<<YouTube link placeholder>>`

---

## Entry 4 — 2025-09-24 — Final checklist and submission preparation
**Goal:** Prepare final documentation, photos, videos, and GitHub repository for submission.  
**Completed items:**
- README.md (English, detailed) prepared.
- engineering_journal exported to PDF.
- Photos of all sides, top & bottom included in `/photos`.
- Two videos (Open & Obstacle) uploaded to YouTube as Unlisted.
- BOM.csv completed.

**Submission checklist (local):**
- Robot dimensions verified: length ≤ 300 mm, width ≤ 200 mm, height ≤ 300 mm.
- Weight measured: `<fill actual weight> kg` (if above 1.5 kg, note reduction steps).
- All wireless modules disabled (none used).
- 3 commits present in Git history.

**Notes for judges:**
- Key innovations: usage of LEGO differential part combined with a Solid Axle steering in Obelix 2.0, modular code architecture on Arduino (and SBC if used), and a practical power management solution using XL4015.
- Engineering factor: custom mounts and differential adaptations made by team; original design contributions include steering geometry and parking routine.

---

## Attachments & file references
- Photos: `/photos/obelix_1_front.jpg`, `/photos/obelix_1_top.jpg`, `/photos/obelix_2_side.jpg`, `/photos/obelix_2_rear.jpg`
- Wiring diagram: `/docs/wiring_diagram.png`
- BOM: `/BOM.csv`
- Code: `/code/*`
- Videos: links in `../videos.txt`

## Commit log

2025-09-05 Update first move
    This repository contains our robot project for the Future Engineers category at WRO. The robot is working, and although current results are modest, it improves with every test. The repository include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
2025-09-21 The first prototype
    [buttompart.stl, converter for motor.stl, details for turning0.stl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]
